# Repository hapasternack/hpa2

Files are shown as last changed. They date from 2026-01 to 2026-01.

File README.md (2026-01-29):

Copyright (c) 2020-2025 Henry A. Pasternack.  All rights reserved.

28-Jan-2026:
The project is up-to-date with KiCad 9.06. There are no ERC or DRC errors.

The project-local footprint library, HPA2-footprints.pretty, contains the following footprints.

   Custom footprints:
   1-pad-wire-connector-22-ga
   2-pad-wire-connector-22-ga
   2-pad-wire-connector-small
   3-pad-wire-connector-22-ga
   HPA-Output-Coil
   Semitec-CRD-SMD

   Legacy footprints to avoid breaking changes to the layout:
   TO-71-6
   D_DO-34_SOD68_P7.62mm_Horizontal
   D_DO-35_SOD27_P7.62mm_Horizontal
   R_0805_2012Metric_Pad1.15x1.40mm_HandSolder
   TO-126-3_Vertical
   TSOT-23-5

   All other footprints have been updated from the latest release libraries as of KiCad 9.0.6.

The project-local library, HPA2_symbols, contains the following custom schematic symbols.

   2N5564
   CRD
   ADA4627-1

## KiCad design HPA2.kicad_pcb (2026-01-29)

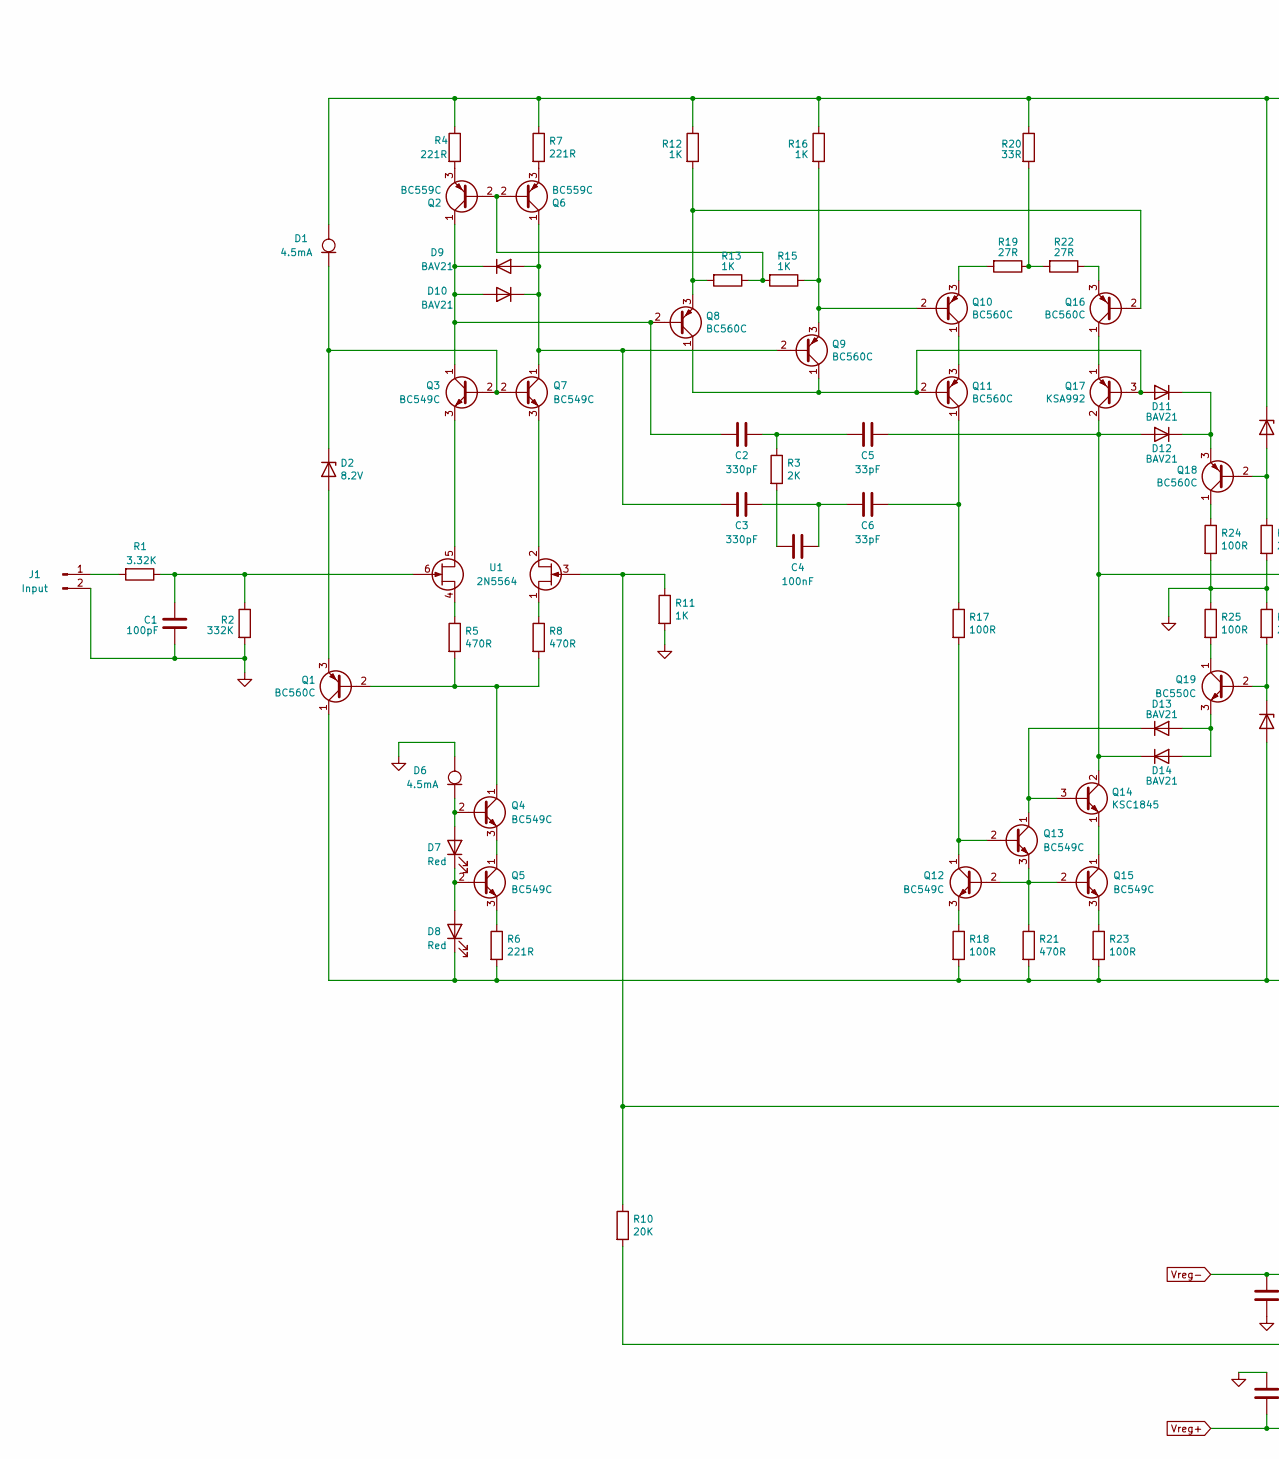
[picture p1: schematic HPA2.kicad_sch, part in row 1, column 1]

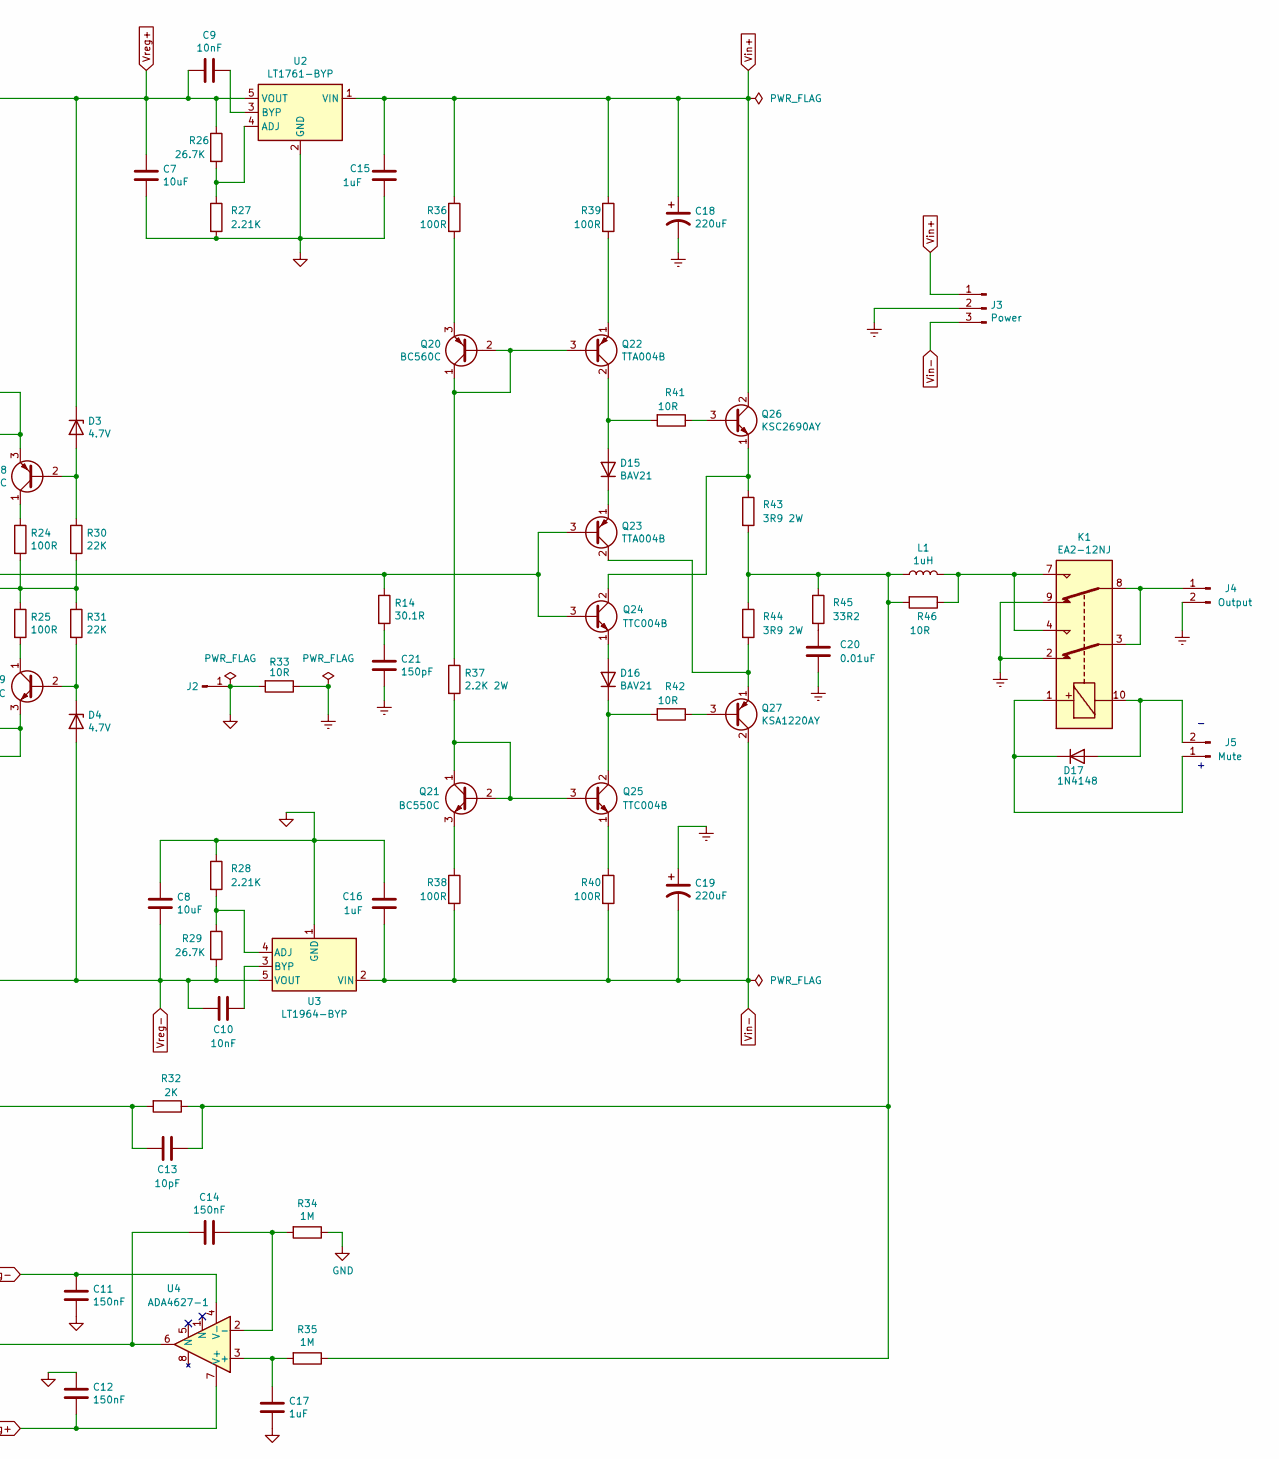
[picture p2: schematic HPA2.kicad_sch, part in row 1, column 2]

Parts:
C1: 100pF; C_Disc_D3.8mm_W2.6mm_P2.50mm
C2, C3: 330pF; C_Disc_D3.8mm_W2.6mm_P2.50mm
C4: 100nF; C_Disc_D3.8mm_W2.6mm_P2.50mm
C5, C6: 33pF; C_Disc_D3.8mm_W2.6mm_P2.50mm
C7, C8: 10uF; C_1206_3216Metric_Pad1.33x1.80mm_HandSolder
C9, C10: 10nF; C_0805_2012Metric_Pad1.18x1.45mm_HandSolder
C11, C12, C14: 150nF; C_Rect_L7.2mm_W2.5mm_P5.00mm_FKS2_FKP2_MKS2_MKP2
C13: 10pF; C_Disc_D3.8mm_W2.6mm_P2.50mm
C15, C16: 1uF; C_1206_3216Metric_Pad1.33x1.80mm_HandSolder
C17: 1uF; C_Rect_L7.2mm_W5.5mm_P5.00mm_FKS2_FKP2_MKS2_MKP2
C18, C19: 220uF; CP_Radial_D10.0mm_P5.00mm
C20: 0.01uF; C_Disc_D4.7mm_W2.5mm_P5.00mm
C21: 150pF; C_Disc_D4.7mm_W2.5mm_P5.00mm
D1, D6: 4.5mA; Semitec-CRD-SMD
D2: 8.2V; D_DO-34_SOD68_P7.62mm_Horizontal
D3, D4: 4.7V; D_DO-34_SOD68_P7.62mm_Horizontal
D7, D8: Red; LED_D3.0mm
D9, D10, D11, D12, D13, D14, D15, D16: BAV21; D_DO-35_SOD27_P7.62mm_Horizontal
D17: 1N4148; D_DO-35_SOD27_P7.62mm_Horizontal
J1: Input; 2-pad-wire-connector-small
J2: Conn_01x01_Male; 1-pad-wire-connector-22-ga
J3: Power; 3-pad-wire-connector-22-ga
J4: Output; 2-pad-wire-connector-small
J5: Mute; 2-pad-wire-connector-22-ga
K1: EA2-12NJ; Relay_DPDT_Omron_G6H-2
L1: 1uH; HPA-Output-Coil
Q1, Q8, Q9, Q10, Q11, Q16, Q18, Q20: BC560C; TO-92_Inline
Q2, Q6: BC559C; TO-92_Inline
Q3, Q4, Q5, Q7, Q12, Q13, Q15: BC549C; TO-92_Inline
Q14: KSC1845; TO-92_Inline
Q17: KSA992; TO-92_Inline
Q19, Q21: BC550C; TO-92_Inline
Q22, Q23: TTA004B; TO-126-3_Vertical
Q24, Q25: TTC004B; TO-126-3_Vertical
Q26: KSC2690AY; TO-126-3_Vertical
Q27: KSA1220AY; TO-126-3_Vertical
R1: 3.32K; R_Axial_DIN0204_L3.6mm_D1.6mm_P5.08mm_Horizontal
R2: 332K; R_Axial_DIN0204_L3.6mm_D1.6mm_P5.08mm_Horizontal
R3: 2K; R_1206_3216Metric
R4, R6, R7: 221R; R_Axial_DIN0204_L3.6mm_D1.6mm_P5.08mm_Horizontal
R5, R8, R21: 470R; R_Axial_DIN0204_L3.6mm_D1.6mm_P5.08mm_Horizontal
R10: 20K; R_Axial_DIN0204_L3.6mm_D1.6mm_P5.08mm_Horizontal
R11, R12, R13, R15, R16: 1K; R_Axial_DIN0204_L3.6mm_D1.6mm_P5.08mm_Horizontal
R14: 30.1R; R_Axial_DIN0204_L3.6mm_D1.6mm_P5.08mm_Horizontal
R17, R18, R23, R24, R25, R36, R38, R39, R40: 100R; R_Axial_DIN0204_L3.6mm_D1.6mm_P5.08mm_Horizontal
R19, R22: 27R; R_Axial_DIN0204_L3.6mm_D1.6mm_P5.08mm_Horizontal
R20: 33R; R_Axial_DIN0204_L3.6mm_D1.6mm_P5.08mm_Horizontal
R26, R29: 26.7K; R_0805_2012Metric_Pad1.15x1.40mm_HandSolder
R27, R28: 2.21K; R_0805_2012Metric_Pad1.15x1.40mm_HandSolder
R30, R31: 22K; R_Axial_DIN0204_L3.6mm_D1.6mm_P5.08mm_Horizontal
R32: 2K; R_Axial_DIN0204_L3.6mm_D1.6mm_P5.08mm_Horizontal
R33, R41, R42, R46: 10R; R_Axial_DIN0207_L6.3mm_D2.5mm_P10.16mm_Horizontal
R34, R35: 1M; R_0805_2012Metric_Pad1.15x1.40mm_HandSolder
R37: 2.2K 2W; R_Axial_DIN0411_L9.9mm_D3.6mm_P12.70mm_Horizontal
R43, R44: 3R9 2W; R_Axial_DIN0411_L9.9mm_D3.6mm_P12.70mm_Horizontal
R45: 33R2; R_Axial_DIN0207_L6.3mm_D2.5mm_P10.16mm_Horizontal
U1: 2N5564; TO-71-6
U2: LT1761-BYP; TSOT-23-5
U3: LT1964-BYP; TSOT-23-5
U4: ADA4627-1; SOIC-8_3.9x4.9mm_P1.27mm

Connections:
GND: C1.2, C7.2, C8.1, C11.2, C12.1, C15.2, C16.2, C17.2, D6.2 (A), J1.2, J2.1, R2.2, R11.2, R24.2, R25.1, R27.2, R28.1, R30.2, R31.1, R33.2, R34.1, U2.2 (GND), U3.1 (GND)
GNDREF: C18.2, C19.1, C20.2, C21.2, J3.2, J4.2, K1.2, K1.9, R33.1
unnamed: C2.1, C5.2, R3.1
unnamed: C3.1, C4.1, C6.2
unnamed: C4.2, R3.2
unnamed: C13.1, L1.2, R32.1, R35.1, R43.2, R44.1, R45.1, R46.2
unnamed: C14.2, R10.2, U4.6
unnamed: C20.1, R45.2
unnamed: C21.1, R14.2
unnamed: D1.1 (K), D2.1 (K), Q3.2 (B), Q7.2 (B)
unnamed: D2.2 (A), Q1.3 (E)
unnamed: D3.2 (A), Q18.2 (B), R30.1
unnamed: D4.1 (K), Q19.2 (B), R31.2
unnamed: D6.1 (K), D7.2 (A), Q4.2 (B)
unnamed: D7.1 (K), D8.2 (A), Q5.2 (B)
unnamed: C2.2, D9.1 (K), D10.2 (A), Q2.1 (C), Q3.1 (C), Q8.2 (B)
unnamed: C3.2, D9.2 (A), D10.1 (K), Q6.1 (C), Q7.1 (C), Q9.2 (B)
unnamed: D11.2 (A), Q8.1 (C), Q9.1 (C), Q11.2 (B), Q17.3 (B)
unnamed: D11.1 (K), D12.1 (K), Q18.3 (E)
unnamed: C5.1, D12.2 (A), D14.1 (K), Q14.2 (C), Q17.2 (C), Q23.3 (B), Q24.3 (B), R14.1
unnamed: D13.2 (A), D14.2 (A), Q19.3 (E)
unnamed: D13.1 (K), Q13.1 (C), Q14.3 (B)
unnamed: D15.2 (A), Q22.2 (C), R41.2
unnamed: D15.1 (K), Q23.1 (E)
unnamed: D16.2 (A), Q24.1 (E)
unnamed: D16.1 (K), Q25.2 (C), R42.2
unnamed: D17.2 (A), J5.2, K1.10
unnamed: D17.1 (K), J5.1, K1.1
unnamed: J1.1, R1.2
unnamed: J4.1, K1.3, K1.8
unnamed: K1.4, K1.7, L1.1, R46.1
unnamed: Q1.2 (B), Q4.1 (C), R5.2, R8.2
unnamed: Q2.2 (B), Q6.2 (B), R13.1, R15.2
unnamed: Q2.3 (E), R4.2
unnamed: Q3.3 (E), U1.5 (2D)
unnamed: Q4.3 (E), Q5.1 (C)
unnamed: Q5.3 (E), R6.1
unnamed: Q6.3 (E), R7.2
unnamed: Q7.3 (E), U1.2 (1D)
unnamed: Q9.3 (E), Q10.2 (B), R15.1, R16.2
unnamed: Q10.1 (C), Q11.3 (E)
unnamed: Q10.3 (E), R19.2
unnamed: C6.1, Q11.1 (C), R17.1
unnamed: Q12.2 (B), Q13.3 (E), Q15.2 (B), R21.1
unnamed: Q12.1 (C), Q13.2 (B), R17.2
unnamed: Q12.3 (E), R18.1
unnamed: Q14.1 (E), Q15.1 (C)
unnamed: Q15.3 (E), R23.1
unnamed: Q8.3 (E), Q16.2 (B), R12.2, R13.2
unnamed: Q16.1 (C), Q17.1 (E)
unnamed: Q16.3 (E), R22.1
unnamed: Q18.1 (C), R24.1
unnamed: Q19.1 (C), R25.2
unnamed: Q20.1 (C), Q20.2 (B), Q22.3 (B), R37.1
unnamed: Q20.3 (E), R36.2
unnamed: Q21.1 (C), Q21.2 (B), Q25.3 (B), R37.2
unnamed: Q21.3 (E), R38.1
unnamed: Q22.1 (E), R39.2
unnamed: Q23.2 (C), Q27.1 (E), R44.2
unnamed: Q24.2 (C), Q26.1 (E), R43.1
unnamed: Q25.1 (E), R40.1
unnamed: Q26.3 (B), R41.1
unnamed: Q27.3 (B), R42.1
unnamed: R19.1, R20.2, R22.2
unnamed: C13.2, R10.1, R11.1, R32.2, U1.3 (1G)
unnamed: R8.1, U1.1 (1S)
unnamed: C1.1, R1.1, R2.1, U1.6 (2G)
unnamed: R5.1, U1.4 (2S)
unnamed: R26.2, R27.1, U2.4 (ADJ)
unnamed: C9.1, U2.3 (BYP)
unnamed: R28.2, R29.1, U3.4 (ADJ)
unnamed: C10.1, U3.3 (BYP)
unnamed: C17.1, R35.2, U4.3 (+)
unnamed: C14.1, R34.2, U4.2 (-)
Vin+: C15.1, C18.1, J3.1, Q26.2 (C), R36.1, R39.1, U2.1 (VIN)
Vin-: C16.1, C19.2, J3.3, Q27.2 (C), R38.2, R40.2, U3.2 (VIN)
Vreg+: C7.1, C9.2, C12.2, D1.2 (A), D3.1 (K), R4.1, R7.1, R12.1, R16.1, R20.1, R26.1, U2.5 (VOUT), U4.7 (V+)
Vreg-: C8.2, C10.2, C11.1, D4.2 (A), D8.1 (K), Q1.1 (C), R6.2, R18.2, R21.2, R23.2, R29.2, U3.5 (VOUT), U4.4 (V-)

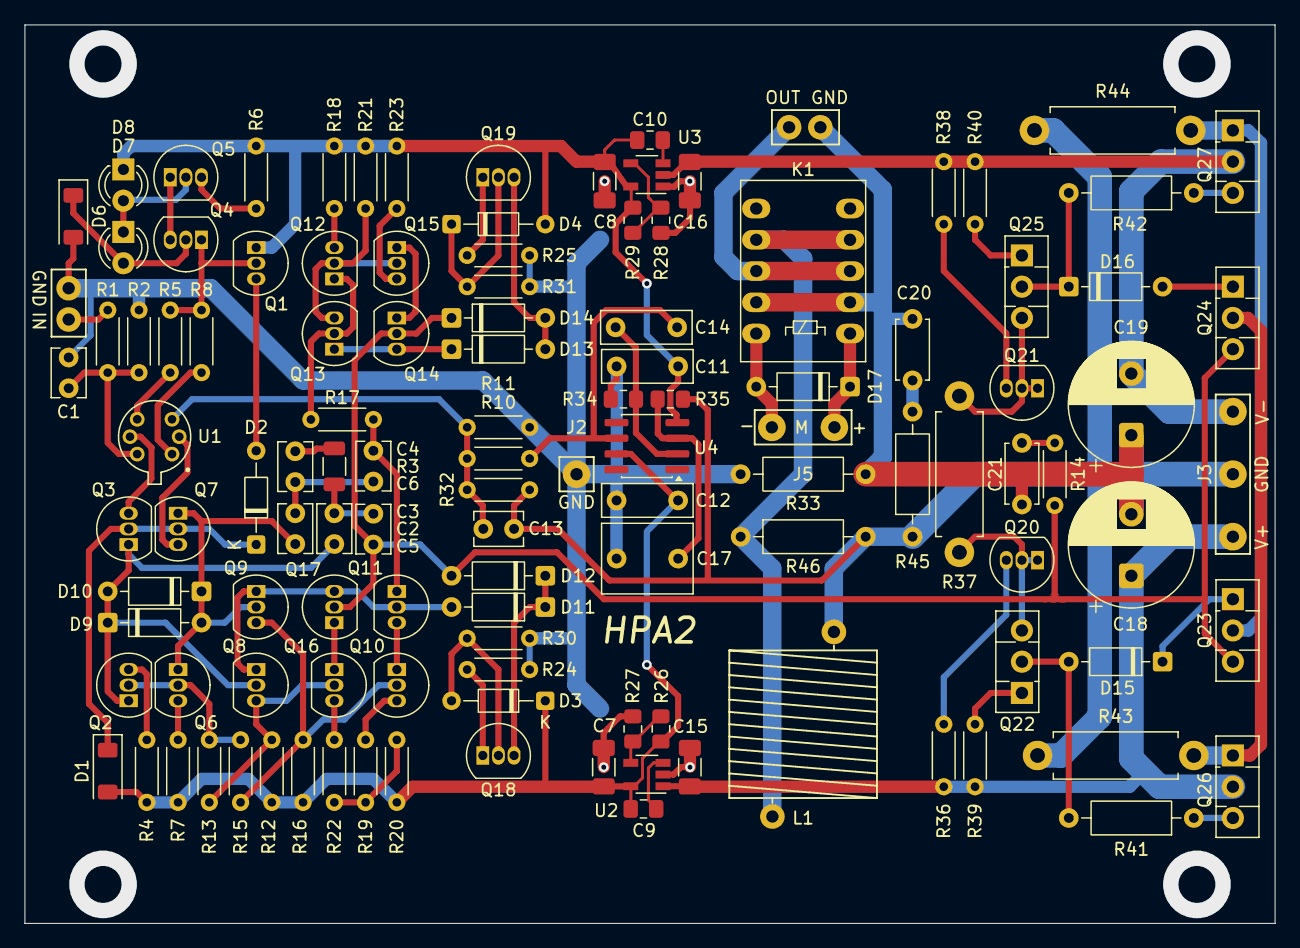
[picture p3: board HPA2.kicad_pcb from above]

Board: 2 copper layers, 101.6 x 73.0 mm, 120 parts (0 on the bottom side), 78 nets.

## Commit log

2025-12-11 Removing legacy files from project.
    [HPA2.sch]
2026-01-21 On the schematic: - Aligned schematic to grid. - Changed all default library transistor symbols to generic Q_PNP/Q_NPN symbols. - Updated other out-of-date default library symbols - Added GND_PWR fla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
    [HPA2.kicad_sch]
2026-01-28 - Created project-local symbol library - Copied custom 2N5564, CRD, and ADA4627-1 symbols to the library - Deleted HPA2-rescue library
    [HPA2.kicad_sch]
2026-01-28 - Removed useless triangular copper pours at trace butt joints - Separated footprints of thermally connected transistor pairs to fix DRC warnings
    [HPA2.kicad_pcb]
2026-01-28 Loaded the existing TSOT-23-5 footprint from the board and saved it to the project-local footprint library. Updated the board. This prevents breaking the U2 regulator layout when updating from latest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
    [HPA2.kicad_pcb]
2026-01-28 Copied the HPA-Output-Coil footprint to the project-local library and updated the board.
    [HPA2.kicad_pcb]
2026-01-28 Updated DO-34 footprint to move "K" silkscreen to f-fab, and made sure the footprint is in the porject-local library. Updated board.
    [HPA2.kicad_pcb]
2026-01-28 -Added local symbol and footprint libraries to repo -Fixed HPA-Output-Coil courtyard
    [HPA2.kicad_pcb]
2026-01-28 Copied TO-126-3-Vertical footprint into project-local library and updated board.
    [HPA2.kicad_pcb]
2026-01-28 Updated remaining footprints from library except for Resistor_SMD:R_0805_2012Metric_Pad1.15x1.40mm_HandSolder.
    [HPA2.kicad_pcb]
2026-01-28 Vendored Resistor_SMD:R_0805_2012Metric_Pad1.15x1.40mm_HandSolder. Updated board.
    [HPA2.kicad_pcb]
2026-01-28 Added legacy R_0805_2012Metric_Pad1.15x1.40mm_HandSolder footprint to project-local library.
2026-01-28 Updated schematic to be consistent with PCB footprint changes.
    [HPA2.kicad_pcb, HPA2.kicad_sch]
2026-01-29 Added custom wire-to-board footprints. Updated the README.
2026-01-29 Updated AD4627-1 symbol to have unconnected pin 8.
    [HPA2.kicad_pcb, HPA2.kicad_sch]
2026-01-29 Updated symbols and footprints following KiCad update to 9.0.7.
    [HPA2.kicad_pcb, HPA2.kicad_sch]
